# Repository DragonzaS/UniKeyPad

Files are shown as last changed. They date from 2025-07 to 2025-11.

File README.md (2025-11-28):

# UniKeyPad
UniKeyPad is a 11 key macropad, with a rotary encoder and an OLED display. Uses QMK firmware!

I made as introduction for myself to PCB design, and also can be used as minimal numberpad companion for my current TKL keyboard.

## Features
- Simple, two part 3D printed case
- one Rotary Encoder for mode selection, together with 128x32 OLED display for friendly UI.
- 11 Customizable keys

## Case

Together it fits using two 3D printed parts, that are kept together with four M3 screws and heatset inserts.
(Angled stand coming soon, to have same angle as my main keyboard)

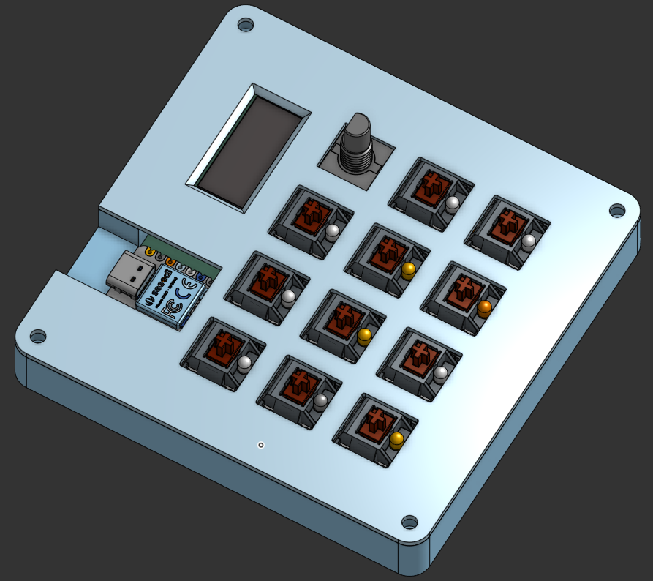
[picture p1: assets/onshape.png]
CAD


All together

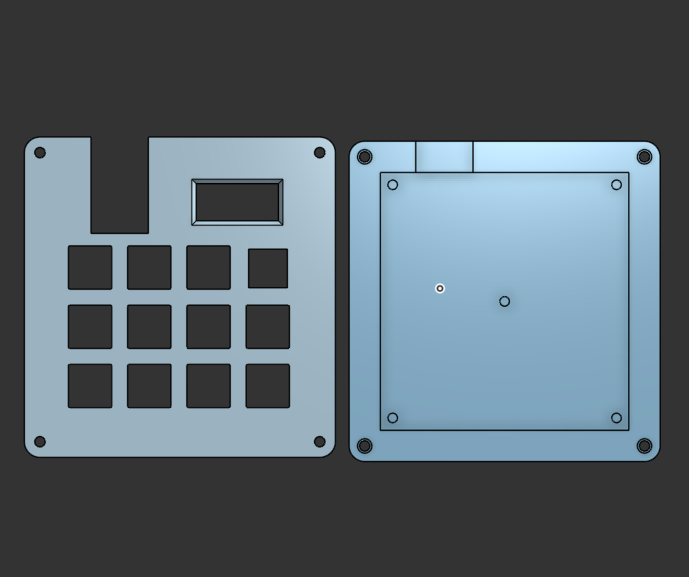
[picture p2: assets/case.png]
Opened case


Case only

Made with OnShape.

(To the reviewer: I added a simplified CAD file, without the switches, the full size one is very big!)
## PCB

Made in Kicad (my first time!). Included also 3D models that I used (they are from GrabCad), it was quite a pain to get them working.

Schematic

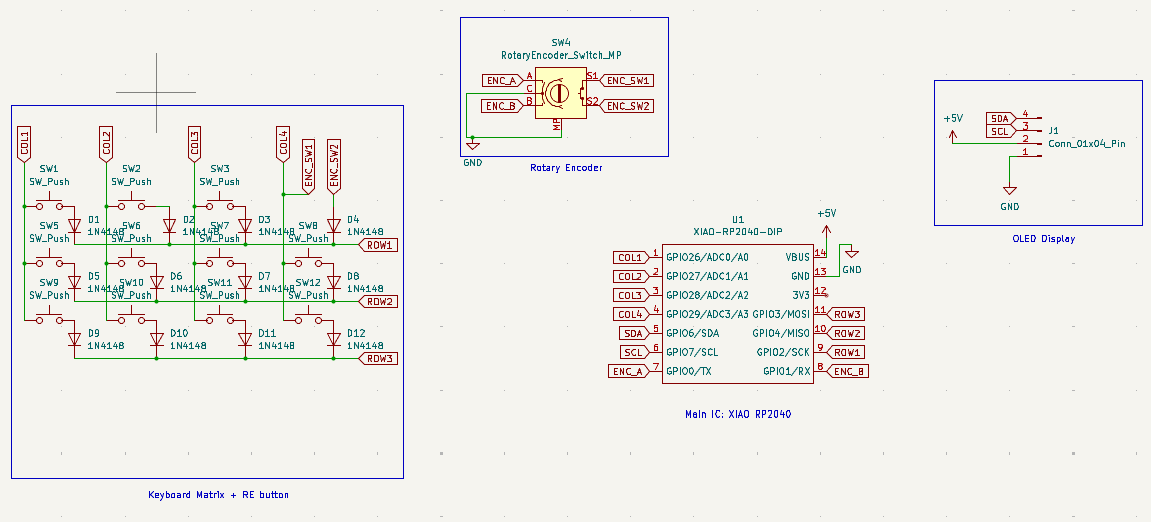
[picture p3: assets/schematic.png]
Schematic


PCB

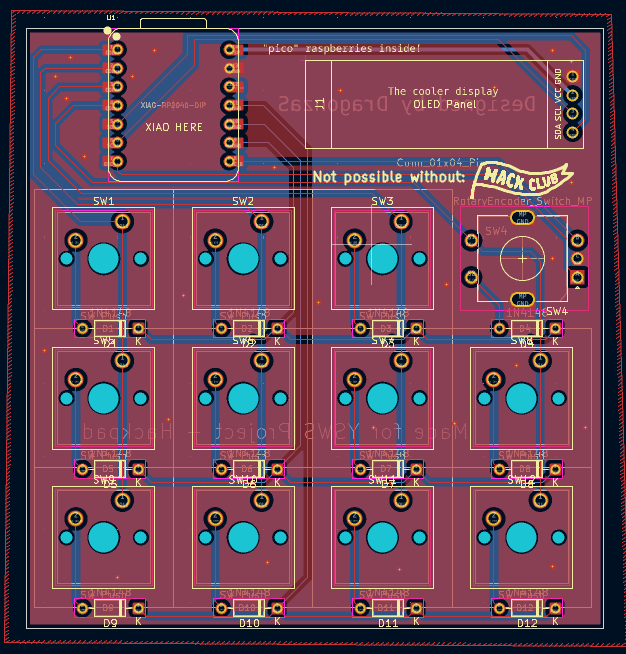
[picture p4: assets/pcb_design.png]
PCB_Design

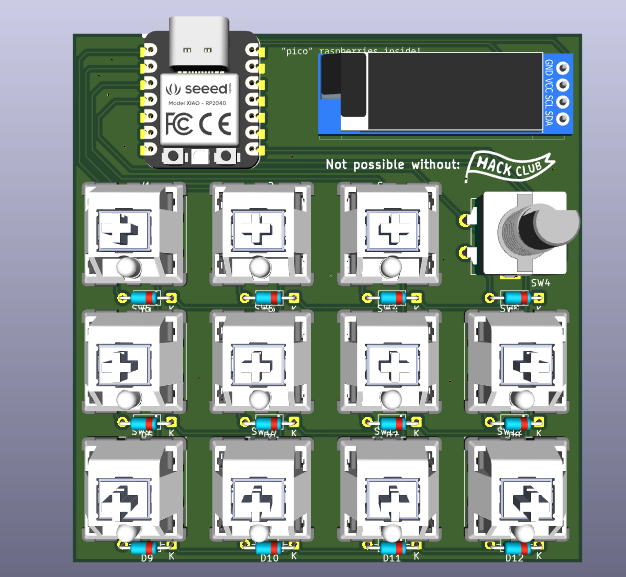
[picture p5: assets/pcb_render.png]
PCB render


Also tried using Ground plane and thicker traces for 5V to OLED for stability.

## Firmware

For now QMK only, might do a KMK version.

OLED is not yet implemented, everything else should work.
Basic functionality tested with a Raspberry Pico and a dupont cable :)
Works!

## Bill of Materials
Hopefully everything that I used:

- 11x Cherry MX Switches
- 11x DSA Keycaps
- 11x 1N4148 Diodes
- 4x M3x5x4 Heatset inserts
- 4x M3x12mm SHCS Bolts
- 1x 0.91" 128x32 OLED Display
- 1x EC11 Rotary Encoder
- 1x XIAO RP2040
- 1x Case, two 3D printed parts (I can print them myself)

## Extra
I enjoyed making it!

Possible thanks to HackClub!

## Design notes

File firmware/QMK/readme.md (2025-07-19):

# unikeypad

unikeypad

*A short description of the keyboard/project*

* Keyboard Maintainer: [DragonzaS](https://github.com/DragonzaS)
* Hardware Supported: *The PCBs, controllers supported*
* Hardware Availability: *Links to where you can find this hardware*

Make example for this keyboard (after setting up your build environment):

    make unikeypad:default

Flashing example for this keyboard:

    make unikeypad:default:flash

See the [build environment setup](https://docs.qmk.fm/#/getting_started_build_tools) and the [make instructions](https://docs.qmk.fm/#/getting_started_make_guide) for more information. Brand new to QMK? Start with our [Complete Newbs Guide](https://docs.qmk.fm/#/newbs).

## Bootloader

Enter the bootloader in 3 ways:

* **Bootmagic reset**: Hold down the key at (0,0) in the matrix (usually the top left key or Escape) and plug in the keyboard
* **Physical reset button**: Briefly press the button on the back of the PCB - some may have pads you must short instead
* **Keycode in layout**: Press the key mapped to `QK_BOOT` if it is available

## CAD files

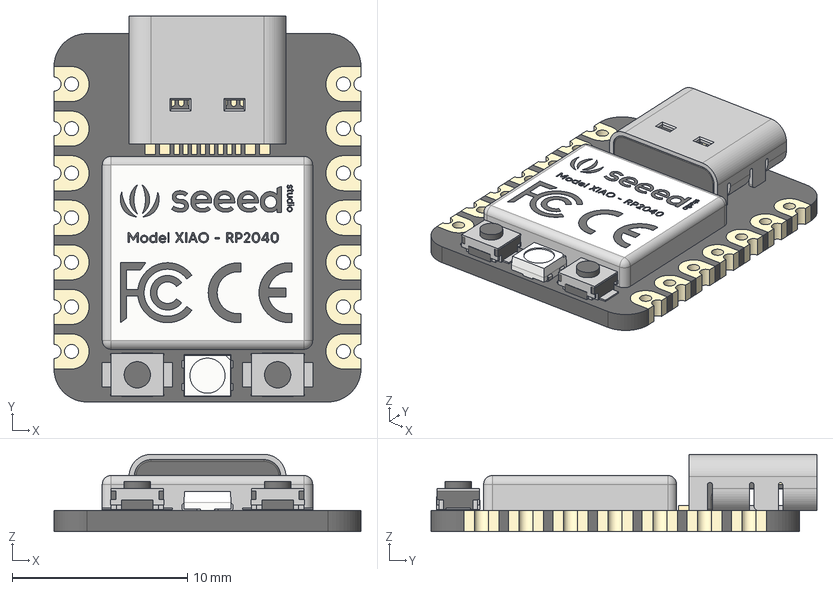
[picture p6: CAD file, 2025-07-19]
pcb/assets/Models/Seeed Studio XIAO RP2040 v26.step
17.5 x 22.0 x 4.40 mm
type-c v2
smd_button v3
DOUT
DIN
VSS
VDD
smd_button v3(Mirror)

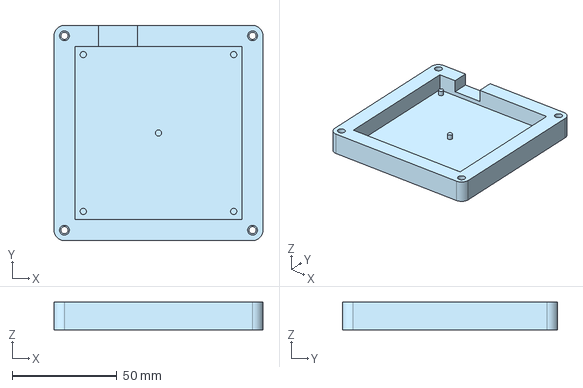
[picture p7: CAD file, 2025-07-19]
production/Bottom.step
100.0 x 103.0 x 13.2 mm

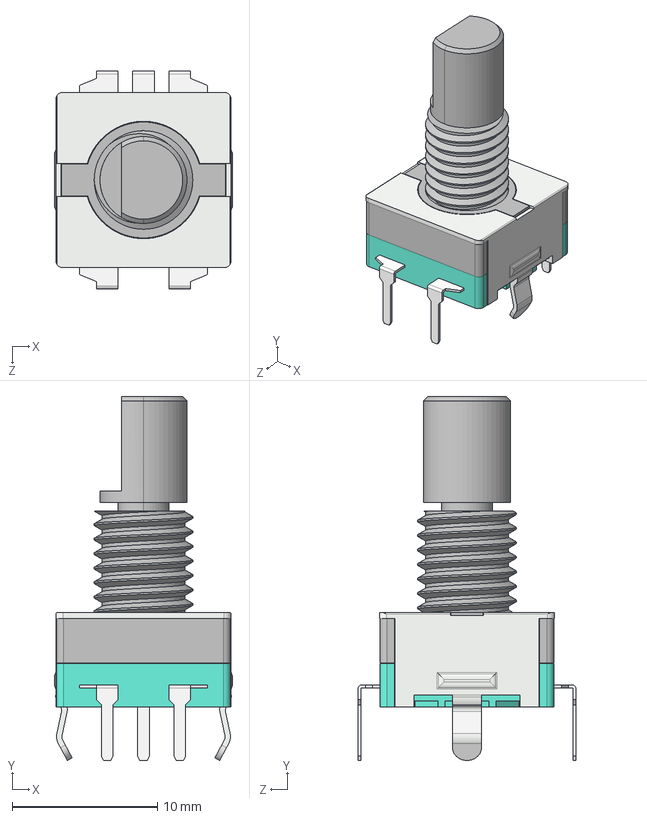
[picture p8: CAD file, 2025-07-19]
pcb/assets/Models/EC11.STEP
12.3 x 25.1 x 15.0 mm

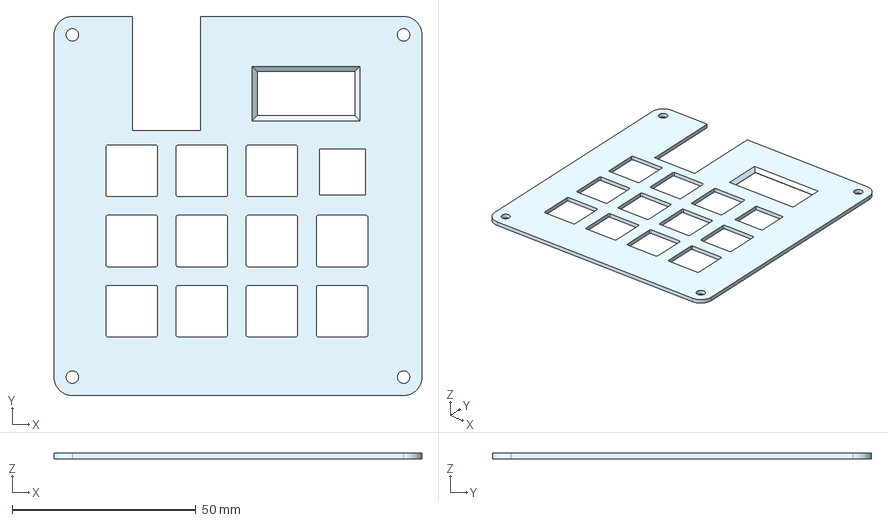
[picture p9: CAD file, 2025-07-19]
production/Top.step
100.0 x 103.0 x 1.50 mm

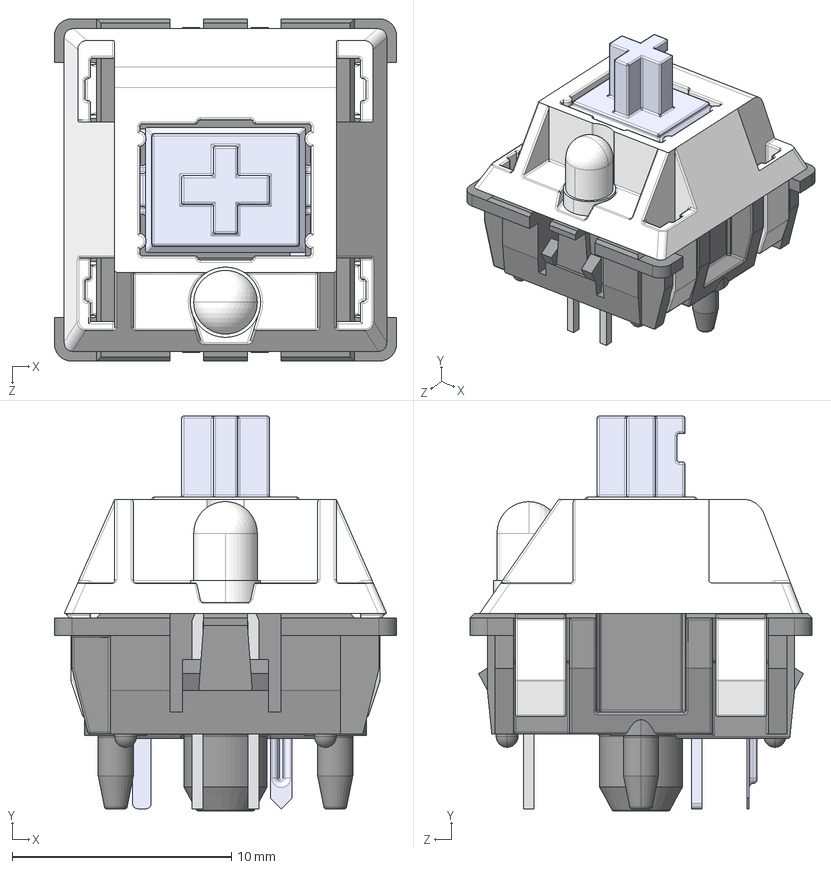
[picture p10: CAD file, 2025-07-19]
pcb/assets/Models/Cherry MX.STEP
15.6 x 18.0 x 15.6 mm
Bottom
Pulsador
Top
Pieza5^Cherry MX
Pin1
Pin2
Led 3mm_trans

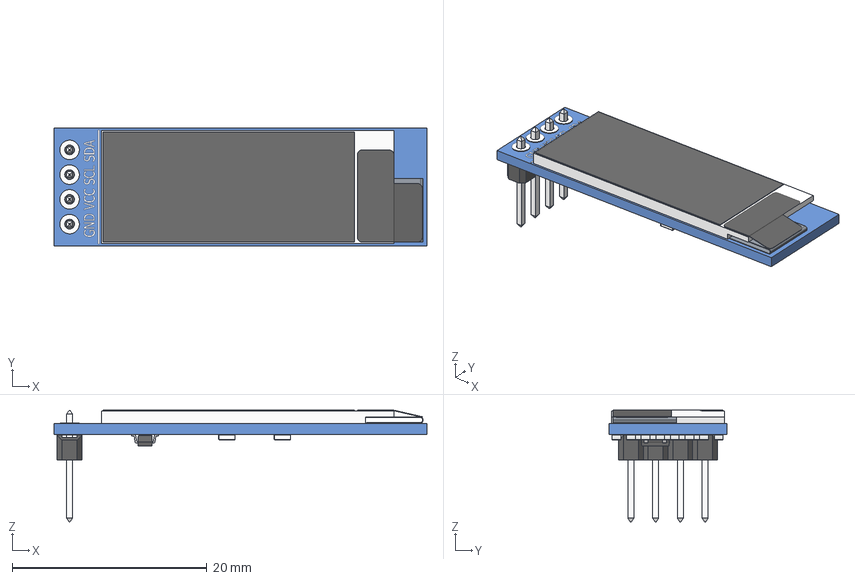
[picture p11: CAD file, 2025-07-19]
pcb/assets/Models/OLED_0.91_128x32.stp
38.3 x 12.1 x 11.5 mm
OLED_0.91_128x32
Pin Header 4 x 1 TH 2.54mm Pitch
RESC-0603 x 13
2SD0601A

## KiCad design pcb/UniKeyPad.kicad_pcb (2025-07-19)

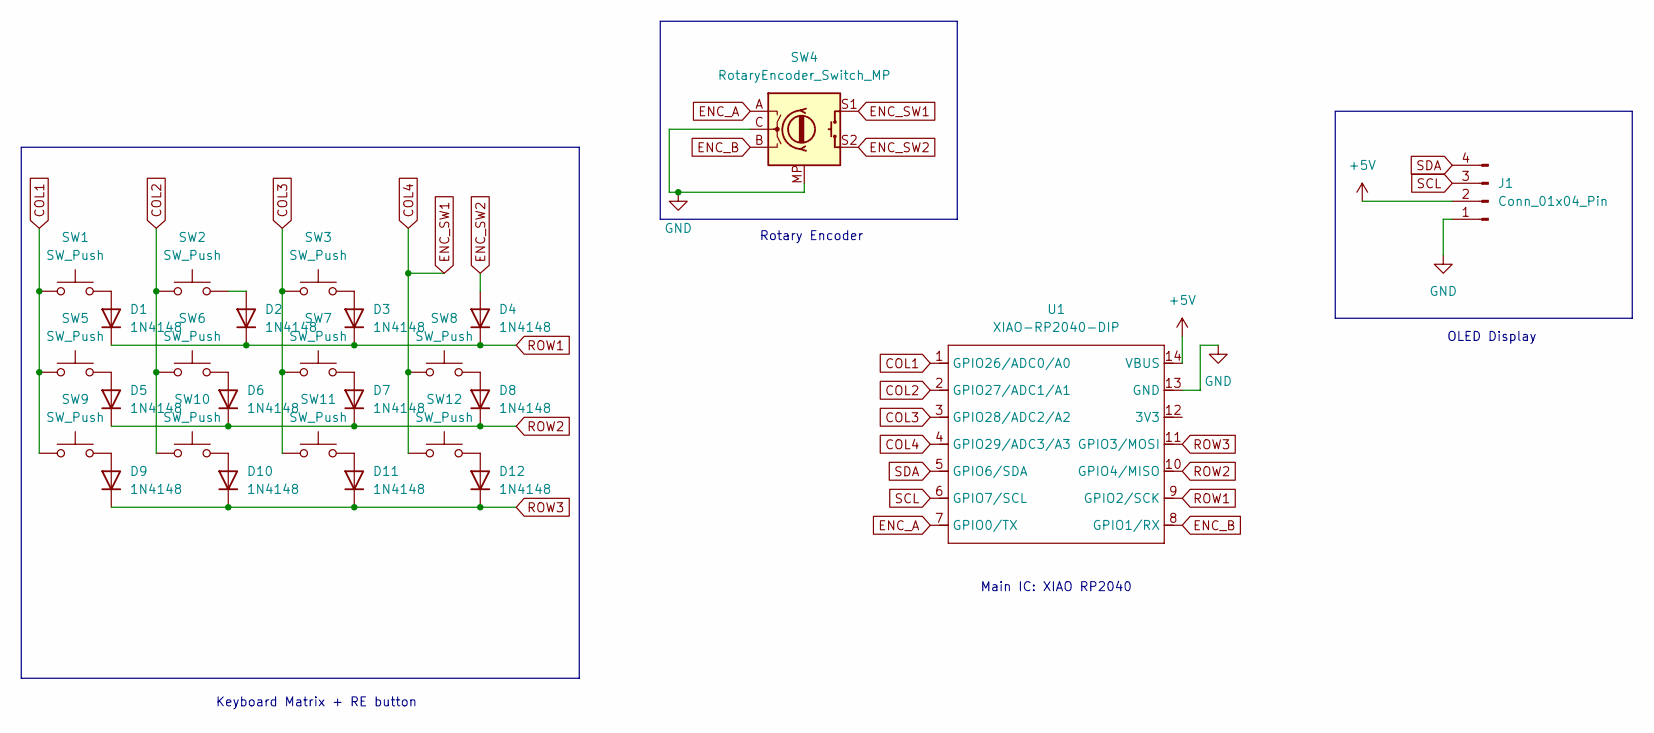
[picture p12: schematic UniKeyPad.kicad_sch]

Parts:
D1, D2, D3, D4, D5, D6, D7, D8, D9, D10, D11, D12: 1N4148; D_DO-35_SOD27_P7.62mm_Horizontal
J1: Conn_01x04_Pin; SSD1306-0.91-OLED-4pin-128x32
SW1, SW2, SW3, SW5, SW6, SW7, SW8, SW9, SW10, SW11, SW12: SW_Push; SW_Cherry_MX_1.00u_PCB_3D
SW4: RotaryEncoder_Switch_MP; RotaryEncoder_Alps_EC11E-Switch_Vertical_H20mm
U1: XIAO-RP2040-DIP

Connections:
+5V: J1.2, U1.14 (VBUS)
COL1: SW1.1, SW5.1, SW9.1, U1.1 (GPIO26/ADC0/A0)
COL2: SW2.1, SW6.1, SW10.1, U1.2 (GPIO27/ADC1/A1)
COL3: SW3.1, SW7.1, SW11.1, U1.3 (GPIO28/ADC2/A2)
COL4: SW4.S1, SW8.1, SW12.1, U1.4 (GPIO29/ADC3/A3)
ENC_A: SW4.A, U1.7 (GPIO0/TX)
ENC_B: SW4.B, U1.8 (GPIO1/RX)
ENC_SW2: D4.2 (A), SW4.S2
GND: J1.1, SW4.C, SW4.MP, U1.13 (GND)
unnamed: D1.2 (A), SW1.2
unnamed: D2.2 (A), SW2.2
unnamed: D3.2 (A), SW3.2
unnamed: D5.2 (A), SW5.2
unnamed: D6.2 (A), SW6.2
unnamed: D7.2 (A), SW7.2
unnamed: D8.2 (A), SW8.2
unnamed: D9.2 (A), SW9.2
unnamed: D10.2 (A), SW10.2
unnamed: D11.2 (A), SW11.2
unnamed: D12.2 (A), SW12.2
ROW1: D1.1 (K), D2.1 (K), D3.1 (K), D4.1 (K), U1.9 (GPIO2/SCK)
ROW2: D5.1 (K), D6.1 (K), D7.1 (K), D8.1 (K), U1.10 (GPIO4/MISO)
ROW3: D9.1 (K), D10.1 (K), D11.1 (K), D12.1 (K), U1.11 (GPIO3/MOSI)
SCL: J1.3, U1.6 (GPIO7/SCL)
SDA: J1.4, U1.5 (GPIO6/SDA)

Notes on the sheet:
Keyboard Matrix + RE button
Rotary Encoder
OLED Display
Main IC: XIAO RP2040

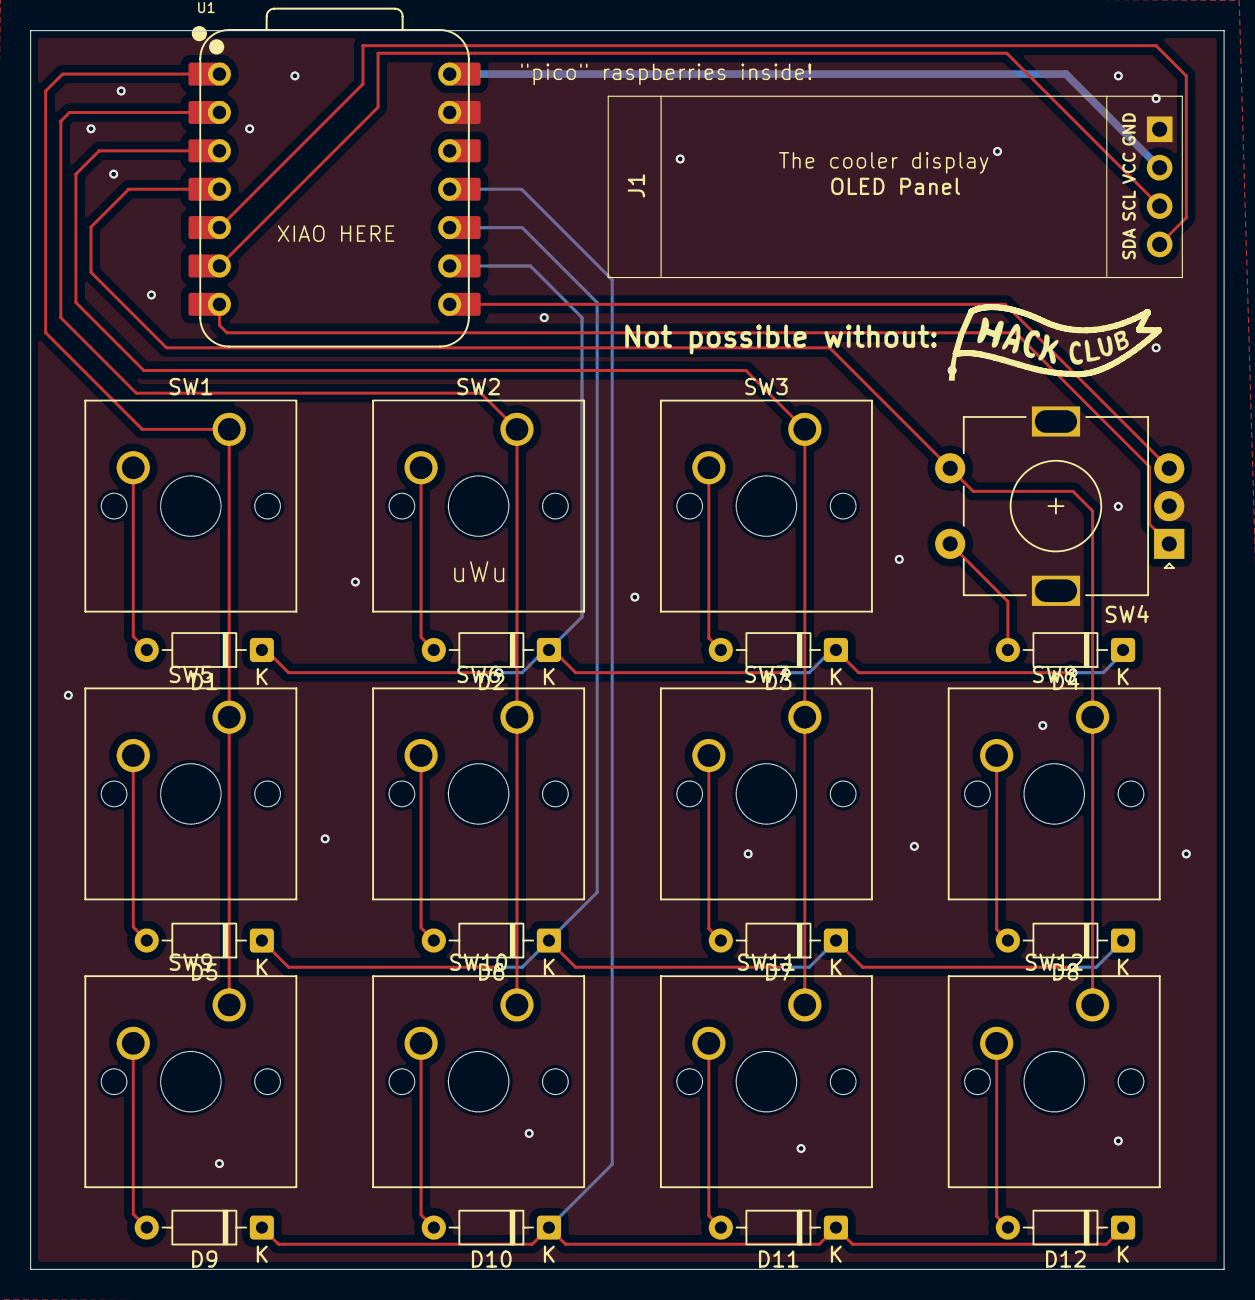
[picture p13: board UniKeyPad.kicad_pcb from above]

Board: 2 copper layers, 79.0 x 82.0 mm, 26 parts (0 on the bottom side), 25 nets.

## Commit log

2025-07-18 Adding backup of Kicad Project
2025-07-18 hopefully everything needed is included in the Kicad zip file
2025-07-18 Create cad
2025-07-18 remove mistaken files
    [UniKeyPad.kicad_pcb, UniKeyPad.kicad_sch]
2025-07-18 Add files via upload
    Files from KiCad
    [UniKeyPad.kicad_pcb, UniKeyPad.kicad_sch]
2025-07-19 Final? PCB folder contents, kicad
    [Cherry MX.STEP, EC11.STEP, OLED_0.91_128x32.stp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]
2025-07-19 forgot these lol
    [UniKeyPad.kicad_pcb, UniKeyPad.kicad_sch]
2025-07-19 Finalizing everything needed, before starting the QMK journey
    [Bottom.step, Top.step]
2025-07-19 Added warning about the CAD file
2025-07-19 Added CASE screenshot
2025-11-28 Fix PCB image source in README
    Updated PCB image source attribute in README.
